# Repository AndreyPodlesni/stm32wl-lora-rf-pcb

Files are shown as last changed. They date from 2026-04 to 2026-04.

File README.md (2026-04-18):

# STM32WL LoRa RF PCB (KiCad)

## Overview
This is a 4-layer PCB design of a LoRa sensor node based on the STM32WLE5CCU6.  
It includes a temperature and humidity sensor (HDC2022) and an RF path to an SMA antenna.  
The board was designed in KiCad with focus on a working hardware setup and easy bring-up.  
The RF section follows the STM32WL development board schematics and layout guidelines.

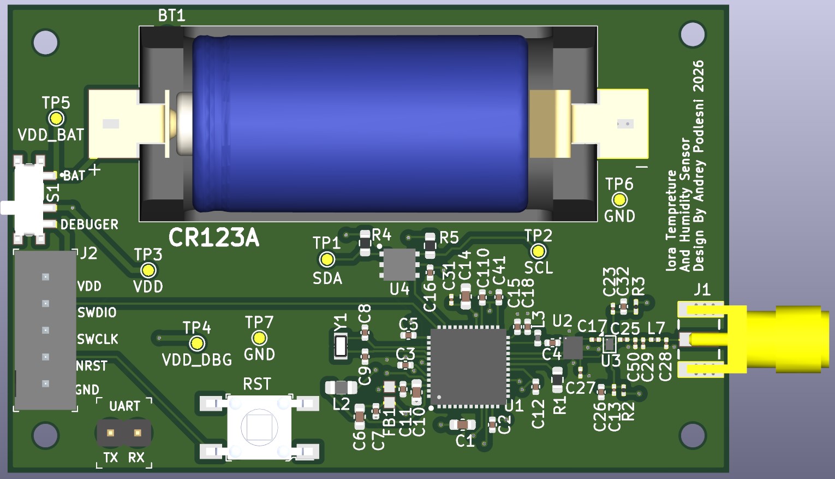
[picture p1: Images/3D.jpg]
3D View


---

## PCB Layout
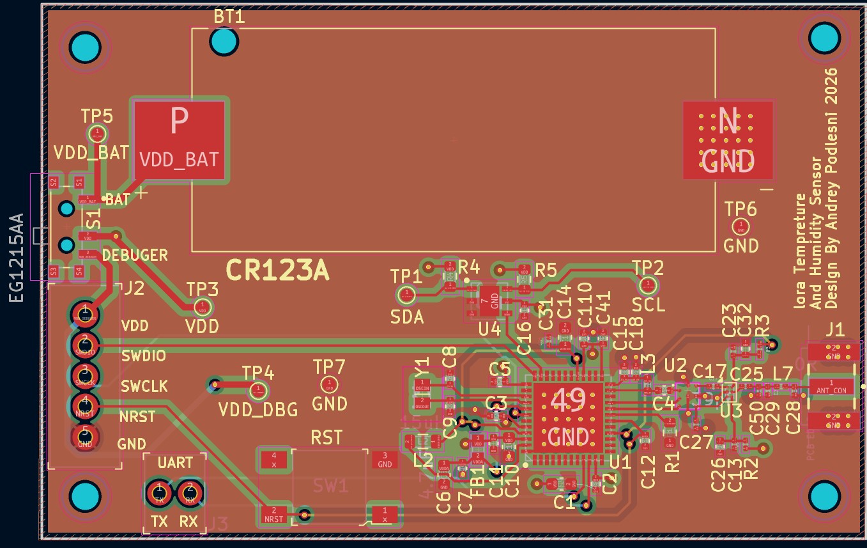
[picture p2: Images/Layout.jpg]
PCB Layout


---

## Key Features  
- STM32WLE5CCU6 (LoRa MCU)  
- HDC2022 temperature & humidity sensor  
- SMA antenna interface  
- 4-layer PCB  
- Battery powered (CR123A)  
- SWD debug interface + UART pins  

---

## Hardware Blocks  
  
### MCU  
STM32WLE5CCU6 with integrated Sub-GHz radio (LoRa).  
Combines MCU and RF transceiver in a single chip, reducing external components and simplifying the design.  

---

### RF Path  
- RF output from the MCU is routed through a matching network to an SMA antenna  
- RF routing implemented as a 50Ω microstrip based on PCB stackup calculations  
- Matching network includes optional components for antenna tuning  

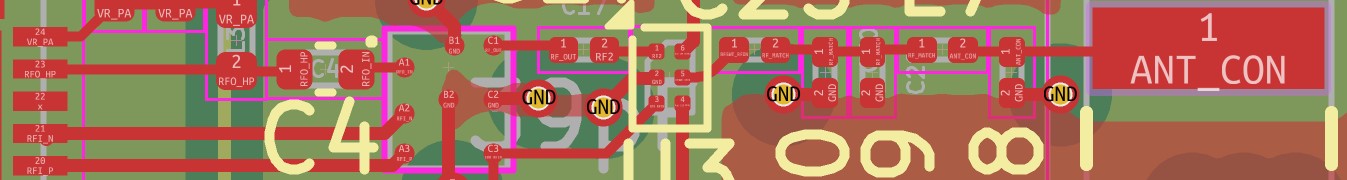
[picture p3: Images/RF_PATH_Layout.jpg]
RF Path


---

### Sensor  
HDC2022 connected over I²C for temperature and humidity measurement  

---

### Battery  
CR123A lithium battery used as the main power source  

Selected for its ability to handle LoRa transmission current peaks and provide reliable long-term operation in a low-duty-cycle system  

Estimated battery life is over 2 years, based on power estimation using STM32CubeMX Power Consumption Calculator  

---

### Debug  
SWD interface and UART pins for programming and debugging  

---

## RF Notes
- RF traces routed as 50Ω controlled impedance  
- Microstrip routing over solid ground plane  
- RF path kept on a single layer (no vias)  

---

## Design Notes
- Matching network allows antenna tuning during testing  
- Battery selected to support LoRa current peaks  
- Power path prevents back-powering during debugging  

---
## Future Improvements
- Refine RF impedance control by considering copper pour clearance and surrounding geometry
- Improve sensor placement to reduce thermal influence from other components
- Further layout optimization for production readiness

## Tools
- KiCad 9  

---

## License
MIT

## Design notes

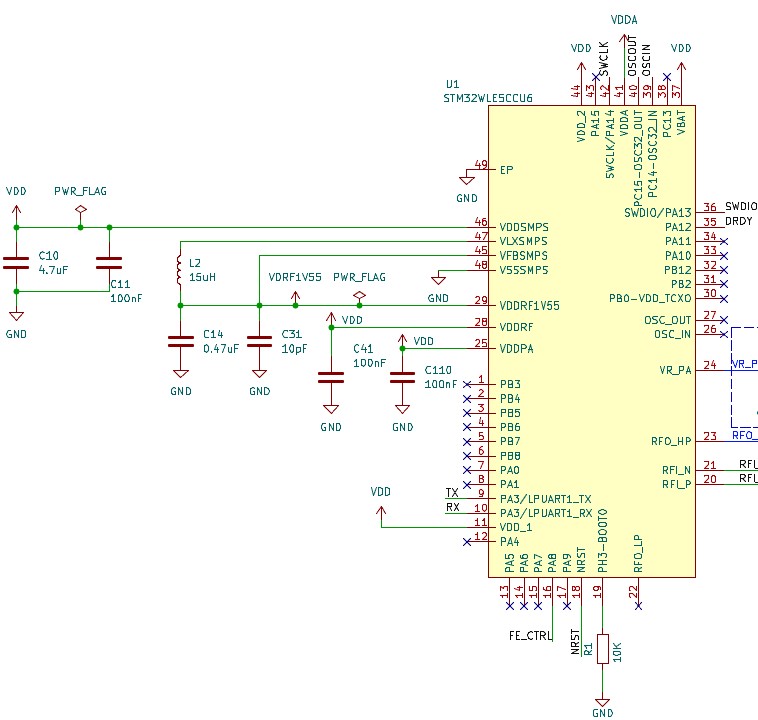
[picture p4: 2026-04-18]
Images/MCU_Schematic.jpg

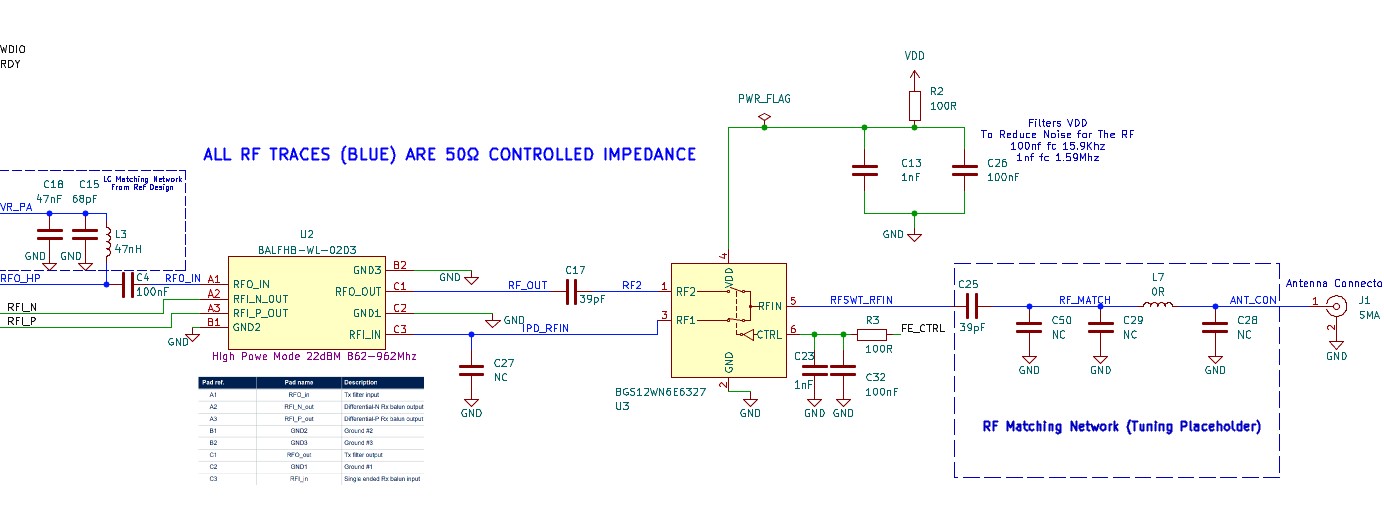
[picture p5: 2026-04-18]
Images/RF_PATH_Schematic.jpg

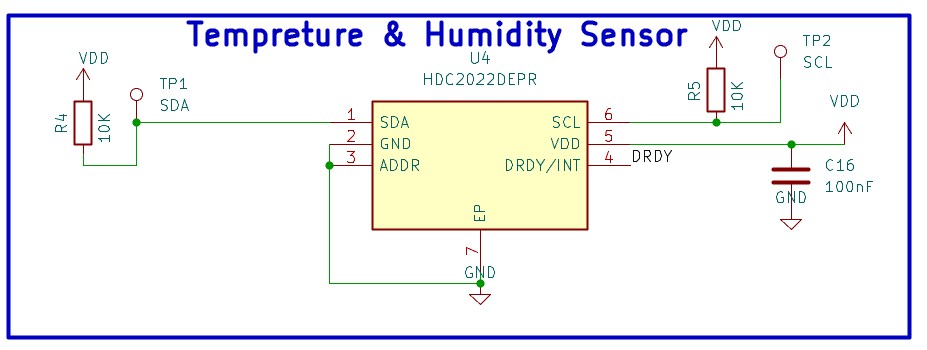
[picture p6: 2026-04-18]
Images/Tempreture_sensor_schematic.jpg

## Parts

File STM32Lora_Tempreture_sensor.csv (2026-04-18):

Reference | Qty | Value | DNP | Exclude from BOM | Exclude from Board | Footprint | Datasheet
BT1 | 1 | CR123A |  |  |  | 1050:BAT_1050 | ~
C1,C6,C10 | 3 | 4.7uF |  |  |  | Capacitor_SMD:C_0603_1608Metric | ~
C2 | 1 | 100nF |  |  |  | Capacitor_SMD:C_0402_1005Metric | ~
C3,C4,C5,C7,C11,C12,C26,C32,C41,C110 | 10 | 100nF |  |  |  | Capacitor_SMD:C_01005_0402Metric | ~
C8,C9 | 2 | 5.1pF |  |  |  | Capacitor_SMD:C_01005_0402Metric | ~
C13,C23 | 2 | 1nF |  |  |  | Capacitor_SMD:C_0201_0603Metric | ~
C14 | 1 | 0.47uF |  |  |  | Capacitor_SMD:C_0603_1608Metric | ~
C15 | 1 | 68pF |  |  |  | Capacitor_SMD:C_01005_0402Metric | ~
C17,C25 | 2 | 39pF |  |  |  | Capacitor_SMD:C_0201_0603Metric | ~
C18 | 1 | 47nF |  |  |  | Capacitor_SMD:C_01005_0402Metric | ~
C27,C28,C29,C50 | 4 | NC |  |  |  | Capacitor_SMD:C_0201_0603Metric | ~
C31 | 1 | 10pF |  |  |  | Capacitor_SMD:C_0201_0603Metric | ~
FB1 | 1 | 600R@100MHz |  |  |  | BLM18AG601SN1D:BEADC1608X95N | ~
H1,H2,H3,H4 | 4 | MountingHole |  | Excluded from BOM |  | MountingHole:MountingHole_4.3mm_M4_ISO14580_Pad | ~
IC1 | 1 | STM32WLE5CCU6 |  |  |  | STM32WLE5CCU6:QFN50P700X700X60-49N-D | https://www.st.com/resource/en/datasheet/stm32wle5c8.pdf
IC2 | 1 | BALFHB-WL-02D3 |  |  |  | BALFHB-WL-02D3:BALFHBWL02D3 | https://www.st.com/resource/en/datasheet/balfhb-wl-02d3.pdf
IC3 | 1 | HDC2022DEPR |  |  |  | HDC2022DERP:SON100P300X300X115-7N-D | https://www.ti.com/lit/ds/symlink/hdc2022.pdf?ts=1611816626574
J1 | 1 | SMA |  |  |  | SMA-J-P-H-ST-EM1:SAMTEC_SMA-J-P-H-ST-EM1 | ~
J2 | 1 | B5B-XH-A_LF__SN_ |  |  |  | digikey-footprints:PinHeader_1x5_P2.5mm_Drill1.1mm | http://www.jst-mfg.com/product/pdf/eng/eXH.pdf
J3 | 1 | 22-23-2021 |  |  |  | digikey-footprints:PinHeader_1x2_P2.54mm_Drill1.02mm | https://media.digikey.com/pdf/Data%20Sheets/Molex%20PDFs/A-6373-N_Series_Dwg_2010-12-03.pdf
L2 | 1 | 15uH |  |  |  | Inductor_SMD:L_0805_2012Metric | ~
L3 | 1 | 47nH |  |  |  | Inductor_SMD:L_0402_1005Metric | ~
L7 | 1 | 0R |  |  |  | Inductor_SMD:L_0201_0603Metric | ~
R1,R4,R5 | 3 | 10K |  |  |  | Resistor_SMD:R_0603_1608Metric | ~
R2 | 1 | 100R |  |  |  | Resistor_SMD:R_0201_0603Metric | ~
R3 | 1 | 100R |  |  |  | Resistor_SMD:R_0201_0603Metric_Pad0.64x0.40mm_HandSolder | ~
SW1 | 1 | RST |  |  |  | TS04_66_55_BK_260_SMT:SW_TS04-66-55-BK-260-SMT | ~
U1 | 1 | BGS12WN6E6327 |  |  |  | Package_LGA:Infineon_PG-TSNP-6-10_0.7x1.1mm_0.7x1.1mm_P0.4mm | https://www.infineon.com/dgdl/Infineon-BGS12WN6-DataSheet-v02_05-EN.pdf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
Y1 | 1 | 32.768KHz |  |  |  | NX2012SA-32.768K-STD-MUB-1:NX2012SA32768KSTDMUB1 | ~

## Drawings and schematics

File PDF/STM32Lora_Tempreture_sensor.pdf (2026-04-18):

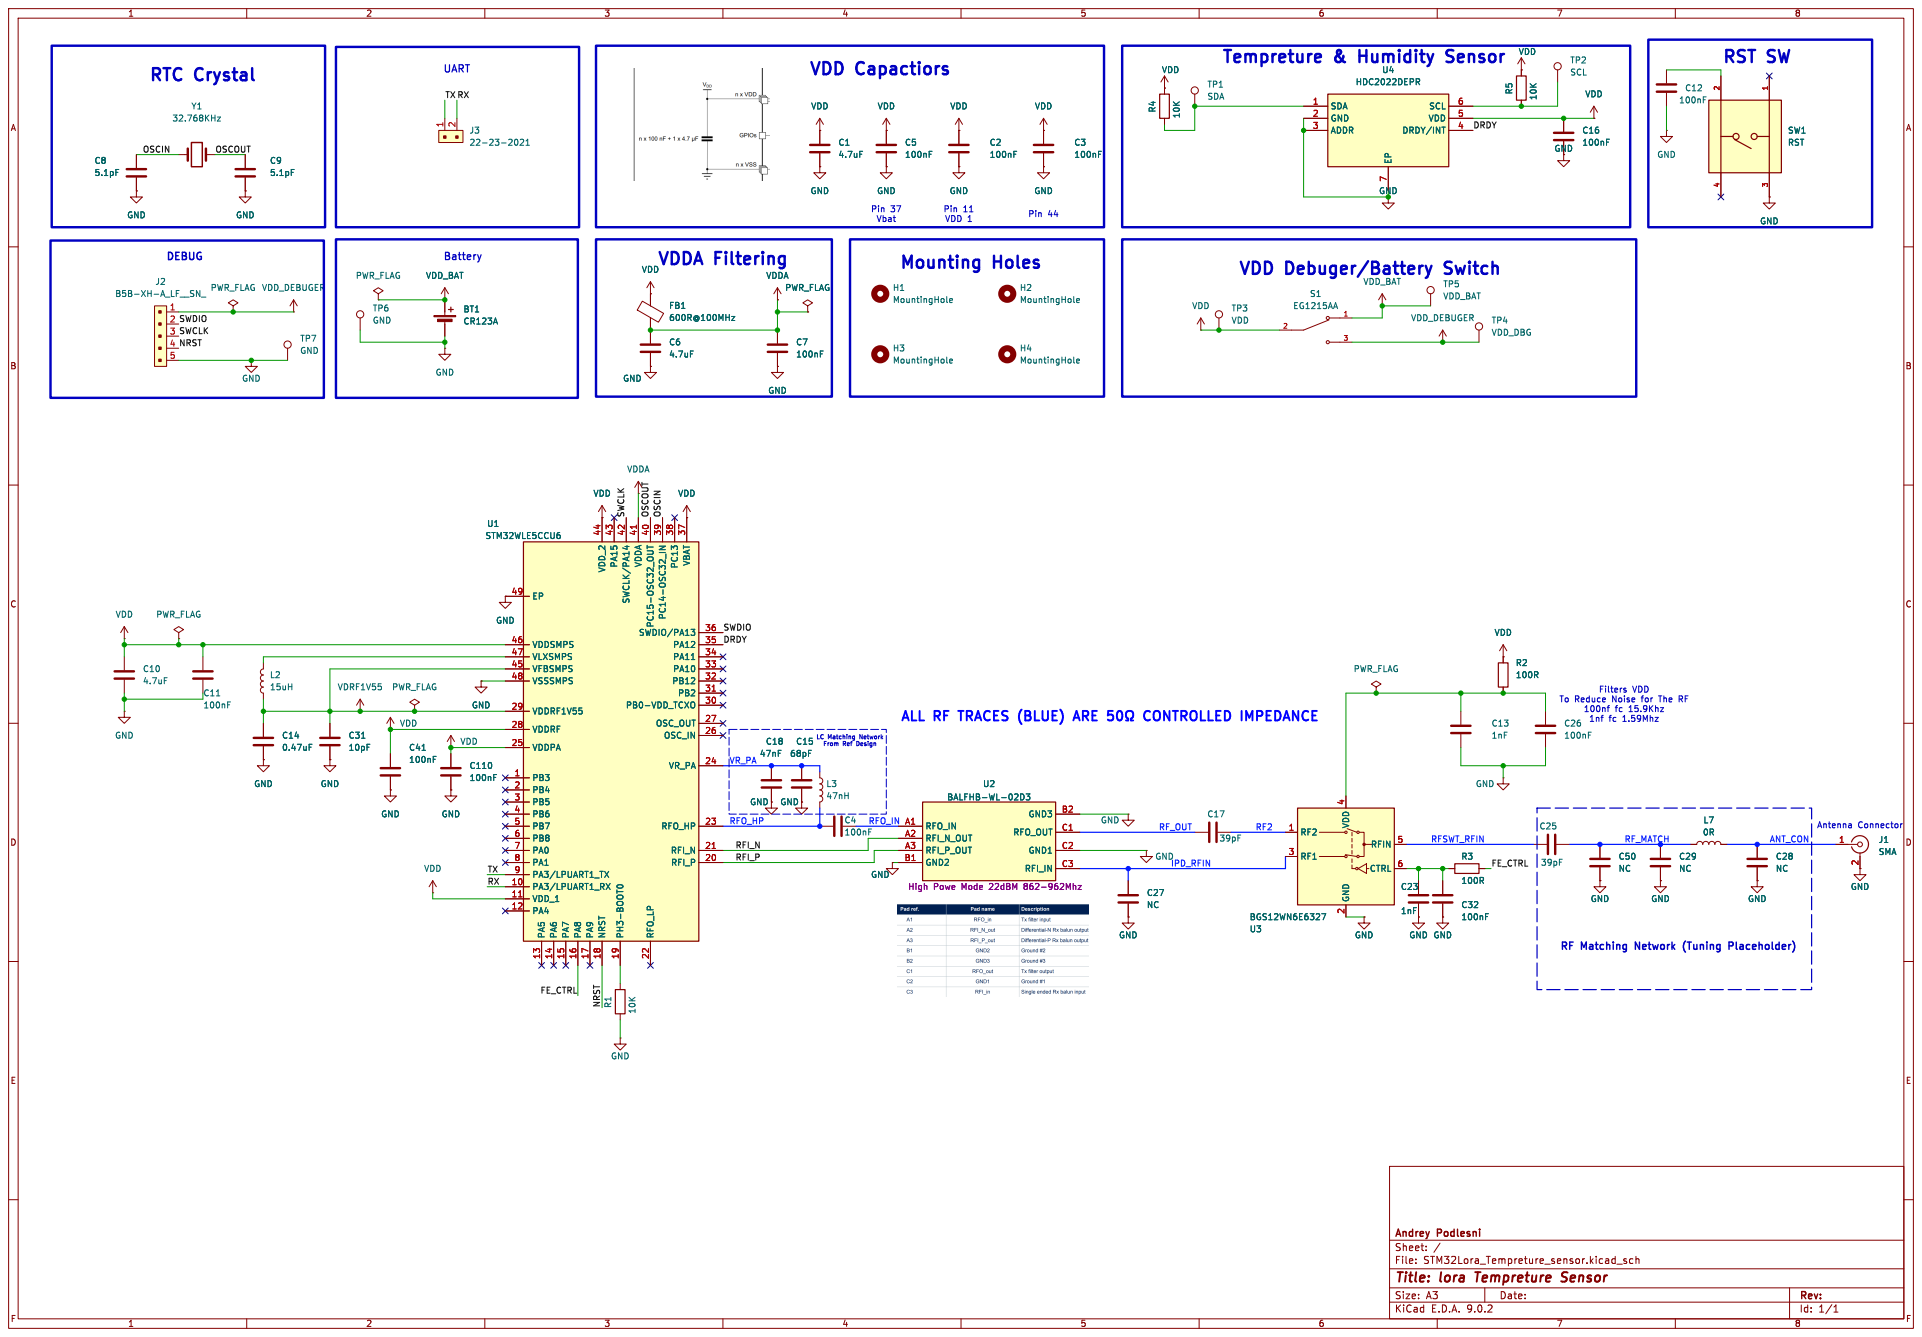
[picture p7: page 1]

7 SCL 6 VDD 5 DRDY/INT 4 U4 HDC2022DEPR GND
RTC Crystal
32.768KHz VDD

7 SCL 6 VDD 5 DRDY/INT 4 GND R4 10K

Pin 11 VDD 1 Pin 37 Vbat DEBUG

To Reduce Noise for The RF
100nf fc 15.9Khz 1nf fc 1.59Mhz

ALL RF TRACES (BLUE) ARE þÿ50©CONTROLLED IMPEDANCE

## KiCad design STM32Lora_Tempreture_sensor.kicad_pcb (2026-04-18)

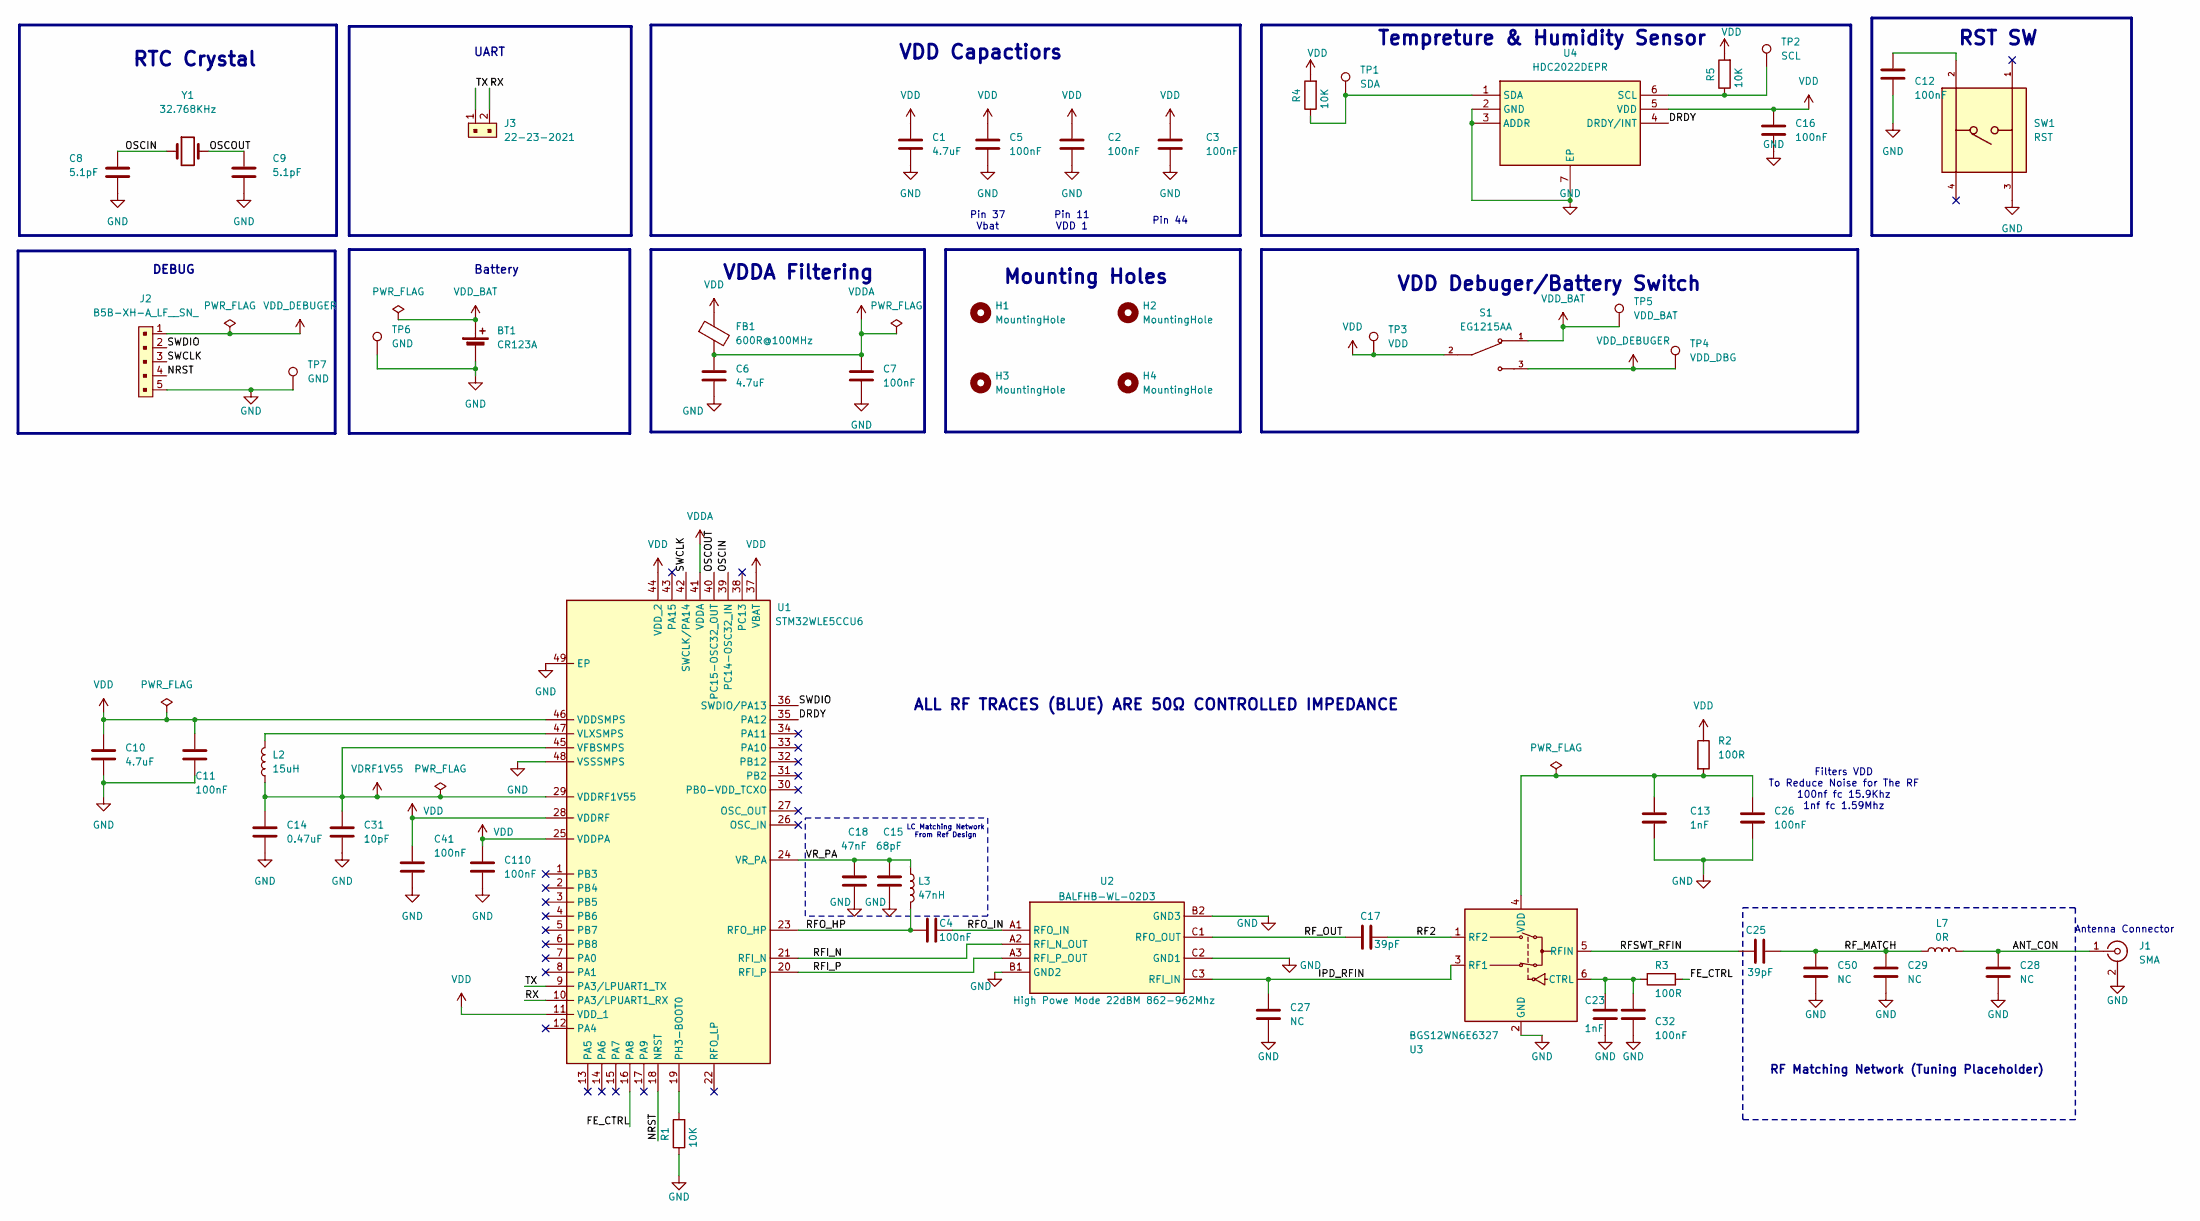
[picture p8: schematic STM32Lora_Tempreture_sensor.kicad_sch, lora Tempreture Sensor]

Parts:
BT1: CR123A; BAT_1050
C1, C6, C10: 4.7uF; C_0603_1608Metric
C2, C3, C4, C5, C7, C11, C12, C16, C26, C32, C41, C110: 100nF; C_0402_1005Metric
C8, C9: 5.1pF; C_0402_1005Metric
C13, C23: 1nF; C_0201_0603Metric
C14: 0.47uF; C_0603_1608Metric
C15: 68pF; C_0402_1005Metric
C17, C25: 39pF; C_0201_0603Metric
C18: 47nF; C_0402_1005Metric
C27, C28, C29, C50: NC; C_0201_0603Metric
C31: 10pF; C_0201_0603Metric
FB1: 600R@100MHz; BEADC1608X95N
H1, H2, H3, H4: MountingHole; MountingHole_2.2mm_M2_ISO14580
J1: SMA; SAMTEC_SMA-J-P-H-ST-EM1
J2: B5B-XH-A_LF__SN_; PinHeader_1x5_P2.5mm_Drill1.1mm; MPN B5B-XH-A(LF)(SN); Digi-Key_PN 455-2270-ND
J3: 22-23-2021; PinHeader_1x2_P2.54mm_Drill1.02mm; MPN 22-23-2021; Digi-Key_PN WM4200-ND
L2: 15uH; L_0805_2012Metric
L3: 47nH; L_0402_1005Metric
L7: 0R; L_0201_0603Metric
R1, R4, R5: 10K; R_0603_1608Metric
R2: 100R; R_0201_0603Metric
R3: 100R; R_0201_0603Metric_Pad0.64x0.40mm_HandSolder
S1: EG1215AA; SW_EG1215AA; PARTREV A
SW1: RST; Switch_Tactile_SMD_6x6mm; PARTREV 1.0
TP1: SDA; TestPoint_Pad_D1.0mm
TP2: SCL; TestPoint_Pad_D1.0mm
TP3: VDD; TestPoint_Pad_D1.0mm
TP4: VDD_DBG; TestPoint_Pad_D1.0mm
TP5: VDD_BAT; TestPoint_Pad_D1.0mm
TP6, TP7: GND; TestPoint_Pad_D1.0mm
U1: STM32WLE5CCU6; QFN50P700X700X60-49N-D; Manufacturer_Part_Number STM32WLE5CCU6; Mouser Part Number 511-STM32WLE5CCU6
U2: BALFHB-WL-02D3; BALFHBWL02D3; Mouser Part Number 511-BALFHB-WL-02D3
U3: BGS12WN6E6327; Infineon_PG-TSNP-6-10_0.7x1.1mm_0.7x1.1mm_P0.4mm
U4: HDC2022DEPR; SON100P300X300X115-7N-D; Mouser Part Number 595-HDC2022DEPR
Y1: 32.768KHz; NX2012SA32768KSTDMUB1

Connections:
/ANT_CON: C28.1, J1.1 (In), L7.2
/DRDY: U1.35 (PA12), U4.4 (DRDY/INT)
/FE_CTRL: R3.1, U1.16 (PA8)
/IPD_RFIN: C27.1, U2.C3 (RFI_IN), U3.3 (RF1)
/OSCIN: C8.1, U1.39 (PC14-OSC32_IN), Y1.1
/OSCOUT: C9.1, U1.40 (PC15-OSC32_OUT), Y1.2
/RF2: C17.2, U3.1 (RF2)
/RFI_N: U1.21 (RFI_N), U2.A2 (RFI_N_OUT)
/RFI_P: U1.20 (RFI_P), U2.A3 (RFI_P_OUT)
/RFO_HP: C4.1, L3.2, U1.23 (RFO_HP)
/RFO_IN: C4.2, U2.A1 (RFO_IN)
/RFSWT_RFIN: C25.1, U3.5 (RFIN)
/RF_MATCH: C25.2, C29.1, C50.1, L7.1
/RF_OUT: C17.1, U2.C1 (RFO_OUT)
/RX: J3.2, U1.10 (PA3/LPUART1_RX)
/SWCLK: J2.3, U1.42 (SWCLK/PA14)
/SWDIO: J2.2, U1.36 (SWDIO/PA13)
/TX: J3.1, U1.9 (PA3/LPUART1_TX)
/VR_PA: C15.1, C18.1, L3.1, U1.24 (VR_PA)
GND: BT1.N (-), C1.2, C2.2, C3.2, C5.2, C6.2, C7.2, C8.2, C9.2, C10.2, C11.2, C12.2, C13.2, C14.2, C15.2, C16.2, C18.2, C23.2, C26.2, C27.2, C28.2, C29.2, C31.2, C32.2, C41.2, C50.2, C110.2, J1.2 (Ext), J2.5, R1.1, SW1.3, TP6.1, TP7.1, U1.48 (VSSSMPS), U1.49 (EP), U2.B1 (GND2), U2.B2 (GND3), U2.C2 (GND1), U3.2 (GND), U4.2 (GND), U4.3 (ADDR), U4.7 (EP)
unnamed: R1.2, U1.19 (PH3-BOOT0)
unnamed: L2.2, U1.47 (VLXSMPS)
unnamed: C23.1, C32.1, R3.2, U3.6 (CTRL)
unnamed: C13.1, C26.1, R2.2, U3.4 (VDD)
unnamed: R5.1, TP2.1, U4.6 (SCL)
unnamed: R4.1, TP1.1, U4.1 (SDA)
VDD: C1.1, C2.1, C3.1, C5.1, C10.1, C11.1, C16.1, C41.1, C110.1, FB1.1, R2.1, R4.2, R5.2, S1.2, TP3.1, U1.11 (VDD_1), U1.25 (VDDPA), U1.28 (VDDRF), U1.37 (VBAT), U1.44 (VDD_2), U1.46 (VDDSMPS), U4.5 (VDD)
VDDA: C6.1, C7.1, FB1.2, U1.41 (VDDA)
VDD_BAT: BT1.P (+), S1.1, TP5.1
VDD_DEBUGER: J2.1, S1.3, TP4.1
VDRF1V55: C14.1, C31.1, L2.1, U1.29 (VDDRF1V55), U1.45 (VFBSMPS)

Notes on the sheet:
Pin 37 Vbat
RTC Crystal
Filters VDD To Reduce Noise for The RF 100nf fc 15.9Khz 1nf fc 1.59Mhz
VDD Debuger/Battery Switch
ALL RF TRACES (BLUE) ARE 50Ω CONTROLLED IMPEDANCE
UART
Pin 44
Antenna Connector
Battery
LC Matching Network From Ref Design
Mounting Holes
VDDA Filtering
RF Matching Network (Tuning Placeholder)
DEBUG
RST SW
VDD Capactiors
Pin 11 VDD 1
Tempreture & Humidity Sensor

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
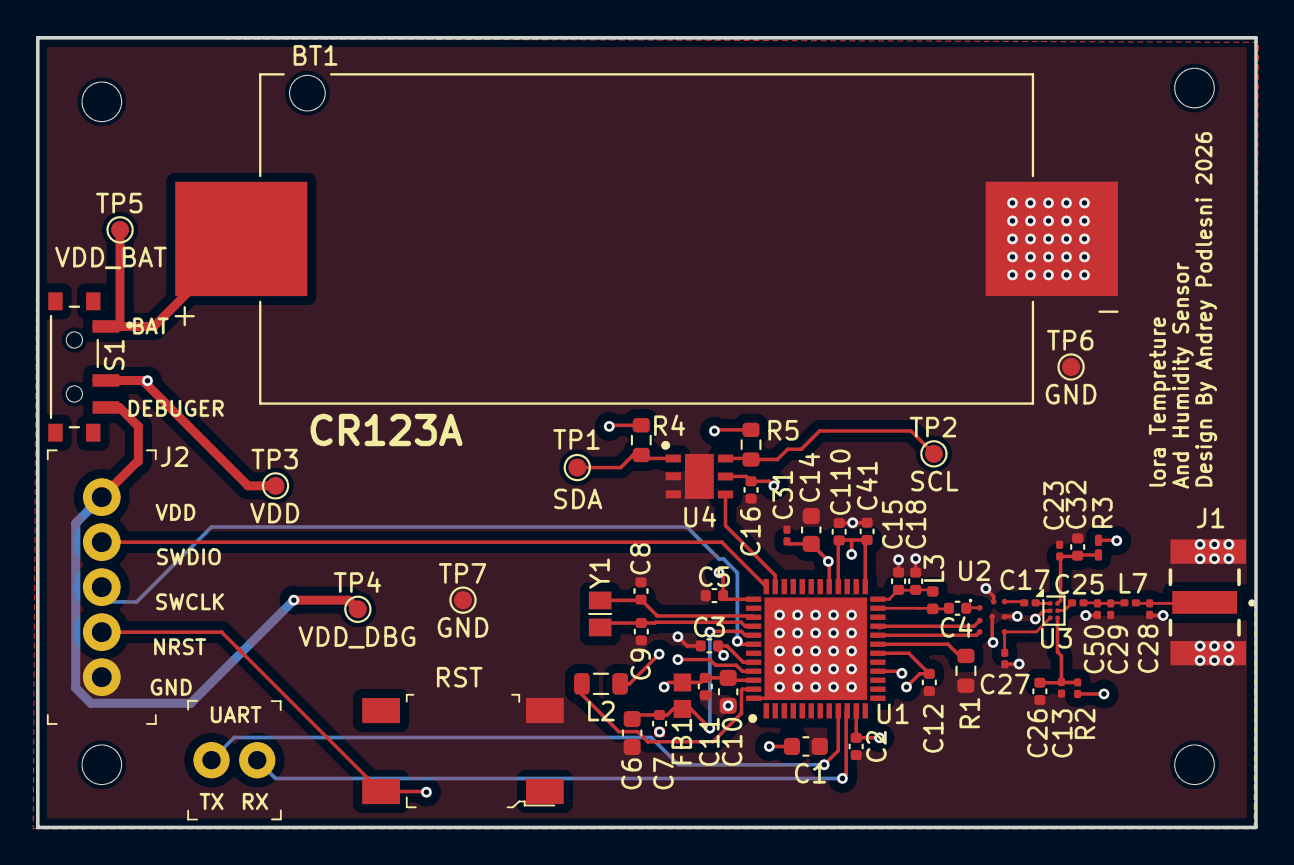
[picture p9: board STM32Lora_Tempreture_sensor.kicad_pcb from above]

Board: 4 copper layers, 67.7 x 43.9 mm, 60 parts (0 on the bottom side), 32 nets.
